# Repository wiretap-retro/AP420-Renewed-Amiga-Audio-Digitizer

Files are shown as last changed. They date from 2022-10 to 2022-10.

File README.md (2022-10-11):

# AP420 Renewed Amiga Audio Digitizer
A remake of the Phoenix Microtechnologies AP420 with mono input and TRS microphone jack.

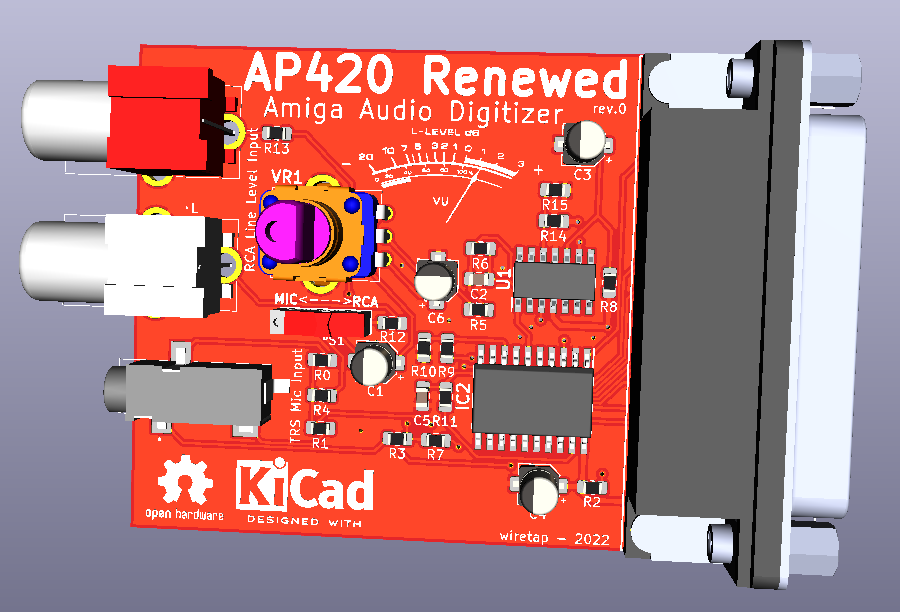
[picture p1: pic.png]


## Information
The schematic is per the PDF manual in the respository from the Phoenix Microtechnologies AP420. I added a second RCA jack so you can hook up stereo sound and it will be combined to a mono input. There's also an updated microphone jack that supports TRS 3.5mm and goes to a mono input. The selector switch on the board allows you to select between the RCA input and the microphone input. VR1 is a gain control knob for adjusting the strength of the audio signal.
\
\
The AP420 manual also goes into some detail in the notes section for performing component changes to allow for different audio sample rates at the expense of audio quality.
\
\
This device hooks up to the parallel port of of an Amiga 500, 600, 1000 (with adapter), 1200, 2000, 3000, and 4000. It does not require any external power.

## Misc
Not built and tested yet. Feel free to evaluate the circuit and provide any feedback.

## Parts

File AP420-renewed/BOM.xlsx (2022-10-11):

Reference | Value | Footprint | Description | Manufacturer_Name | Manufacturer_Part_Number | Mouser Part Number
C1 | 10u | Capacitor_SMD:CP_Elec_4x5.8
C2 | 220p | Capacitor_SMD:C_0805_2012Metric_Pad1.15x1.40mm_HandSolder
C3 | 10u | Capacitor_SMD:CP_Elec_4x5.8
C4 | 10u | Capacitor_SMD:CP_Elec_4x5.8
C5 | 100p | Capacitor_SMD:C_0805_2012Metric_Pad1.15x1.40mm_HandSolder
C6 | 10u | Capacitor_SMD:CP_Elec_4x5.8
IC2 | ADC0804LCWMX_NOPB | SOIC127P1030X265-20N | 8-Bit, 1-Ch P Compatible A/D Converters with 1 LSB INL | Texas Instruments | ADC0804LCWMX/NOPB | 926-ADC0804LCWMXNOPB
J0 | L717SDB25P1ACH4F | L717SDB25P1ACH4F | Dsub, Stamped Signal 3A, Right Angle PCB Through Hole, FP=10.40mm (0.409in), Row Pitch 2.54mm, 25 Pin, Flash Gold, Bright Tin Shell+Grounding Dimples, 4-40 Front Screwlock, Ground Tab with Boardlock | Amphenol | L717SDB25P1ACH4F | 523-L717SDB25P1ACH4F
J1 | SJ-3523-SMT-TR | SJ3523SMTTR | Phone Connectors Audio Jacks | CUI Inc. | SJ-3523-SMT-TR | 490-SJ-3523-SMT-TR
J2 | RCJ-042 | RCJ042 | RCA Phono Connectors RCA Connectors | CUI Inc. | RCJ-042 | 490-RCJ-042
J3 | RCJ-043 | RCJ043 | RCA Phono Connectors RCA Connectors | CUI Inc. | RCJ-042 | 490-RCJ-043
R0 | 10k | Resistor_SMD:R_0805_2012Metric_Pad1.15x1.40mm_HandSolder
R1 | 10k | Resistor_SMD:R_0805_2012Metric_Pad1.15x1.40mm_HandSolder
R10 | 470 | Resistor_SMD:R_0805_2012Metric_Pad1.15x1.40mm_HandSolder
R11 | 1.5k | Resistor_SMD:R_0805_2012Metric_Pad1.15x1.40mm_HandSolder
R12 | 1k | Resistor_SMD:R_0805_2012Metric_Pad1.15x1.40mm_HandSolder
R13 | 1k | Resistor_SMD:R_0805_2012Metric_Pad1.15x1.40mm_HandSolder
R14 | 1M | Resistor_SMD:R_0805_2012Metric_Pad1.15x1.40mm_HandSolder
R15 | 1M | Resistor_SMD:R_0805_2012Metric_Pad1.15x1.40mm_HandSolder
R2 | 2.2k | Resistor_SMD:R_0805_2012Metric_Pad1.15x1.40mm_HandSolder
R3 | 10k | Resistor_SMD:R_0805_2012Metric_Pad1.15x1.40mm_HandSolder
R4 | 1M | Resistor_SMD:R_0805_2012Metric_Pad1.15x1.40mm_HandSolder
R5 | 22k | Resistor_SMD:R_0805_2012Metric_Pad1.15x1.40mm_HandSolder
R6 | 100k | Resistor_SMD:R_0805_2012Metric_Pad1.15x1.40mm_HandSolder
R7 | 22k | Resistor_SMD:R_0805_2012Metric_Pad1.15x1.40mm_HandSolder
R8 | 3.3k | Resistor_SMD:R_0805_2012Metric_Pad1.15x1.40mm_HandSolder
R9 | 1.5k | Resistor_SMD:R_0805_2012Metric_Pad1.15x1.40mm_HandSolder
S1 | 450301014042 | 450301014042 | Mini Slide Switch 10x2.5mm SPDT on / on Through Hole Slide Switch SPDT On-On 100 mA@ 42 V dc Slide | Wurth Elektronik | 450301014042 | 710-450301014042
U1 | LM324DR | SamacSys_Parts:SOIC127P600X175-14N | Operational Amplifiers - Op Amps Quad GP Op Amp | Texas Instruments | LM324DR | 595-LM324DR
VR1 | RK09D1130C1B | RK09D1130C1B | Audio single pot. 10K Vertical 20mm,1B Alps Potentiometer RK09D Series with a 6 mm Dia. Shaft 10k +/-20% 0.05W, Linear, Through Hole | ALPS Electric | RK09D1130C1B | 688-RK09D1130C1B

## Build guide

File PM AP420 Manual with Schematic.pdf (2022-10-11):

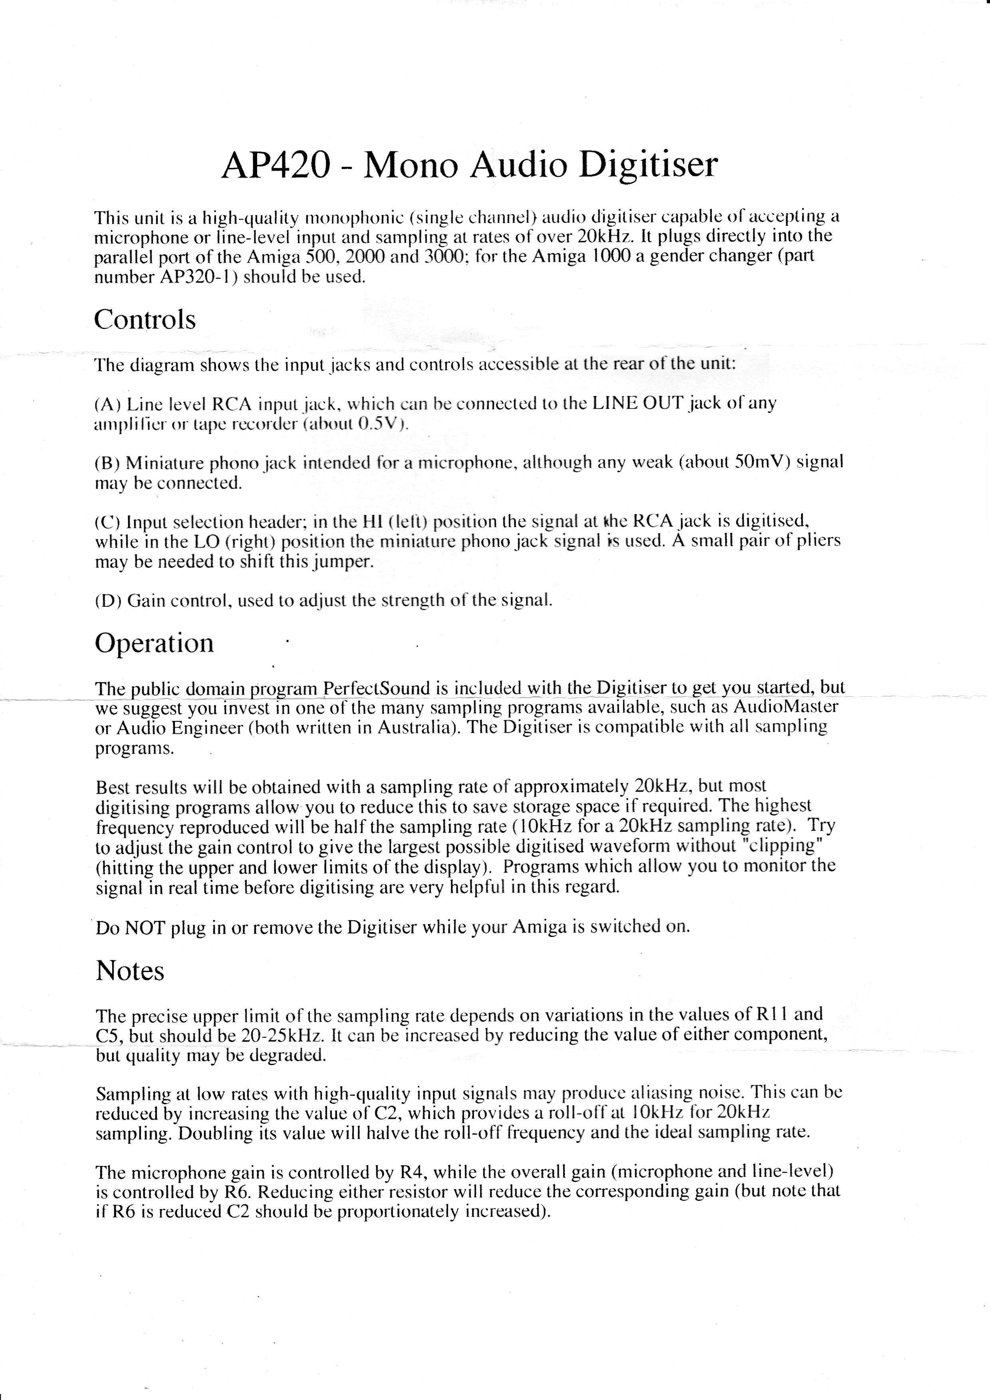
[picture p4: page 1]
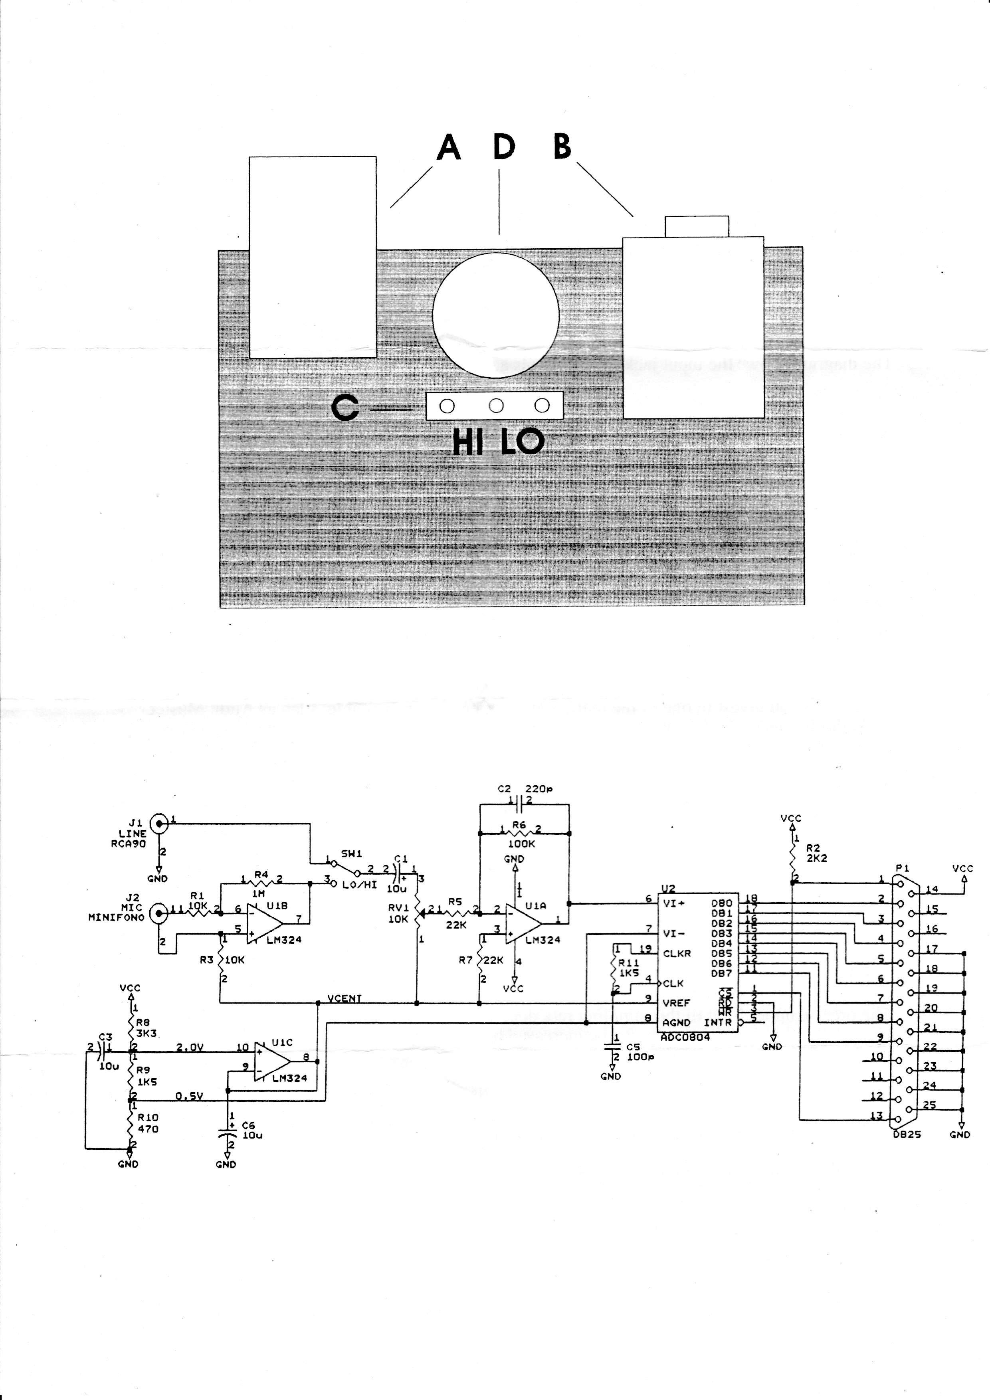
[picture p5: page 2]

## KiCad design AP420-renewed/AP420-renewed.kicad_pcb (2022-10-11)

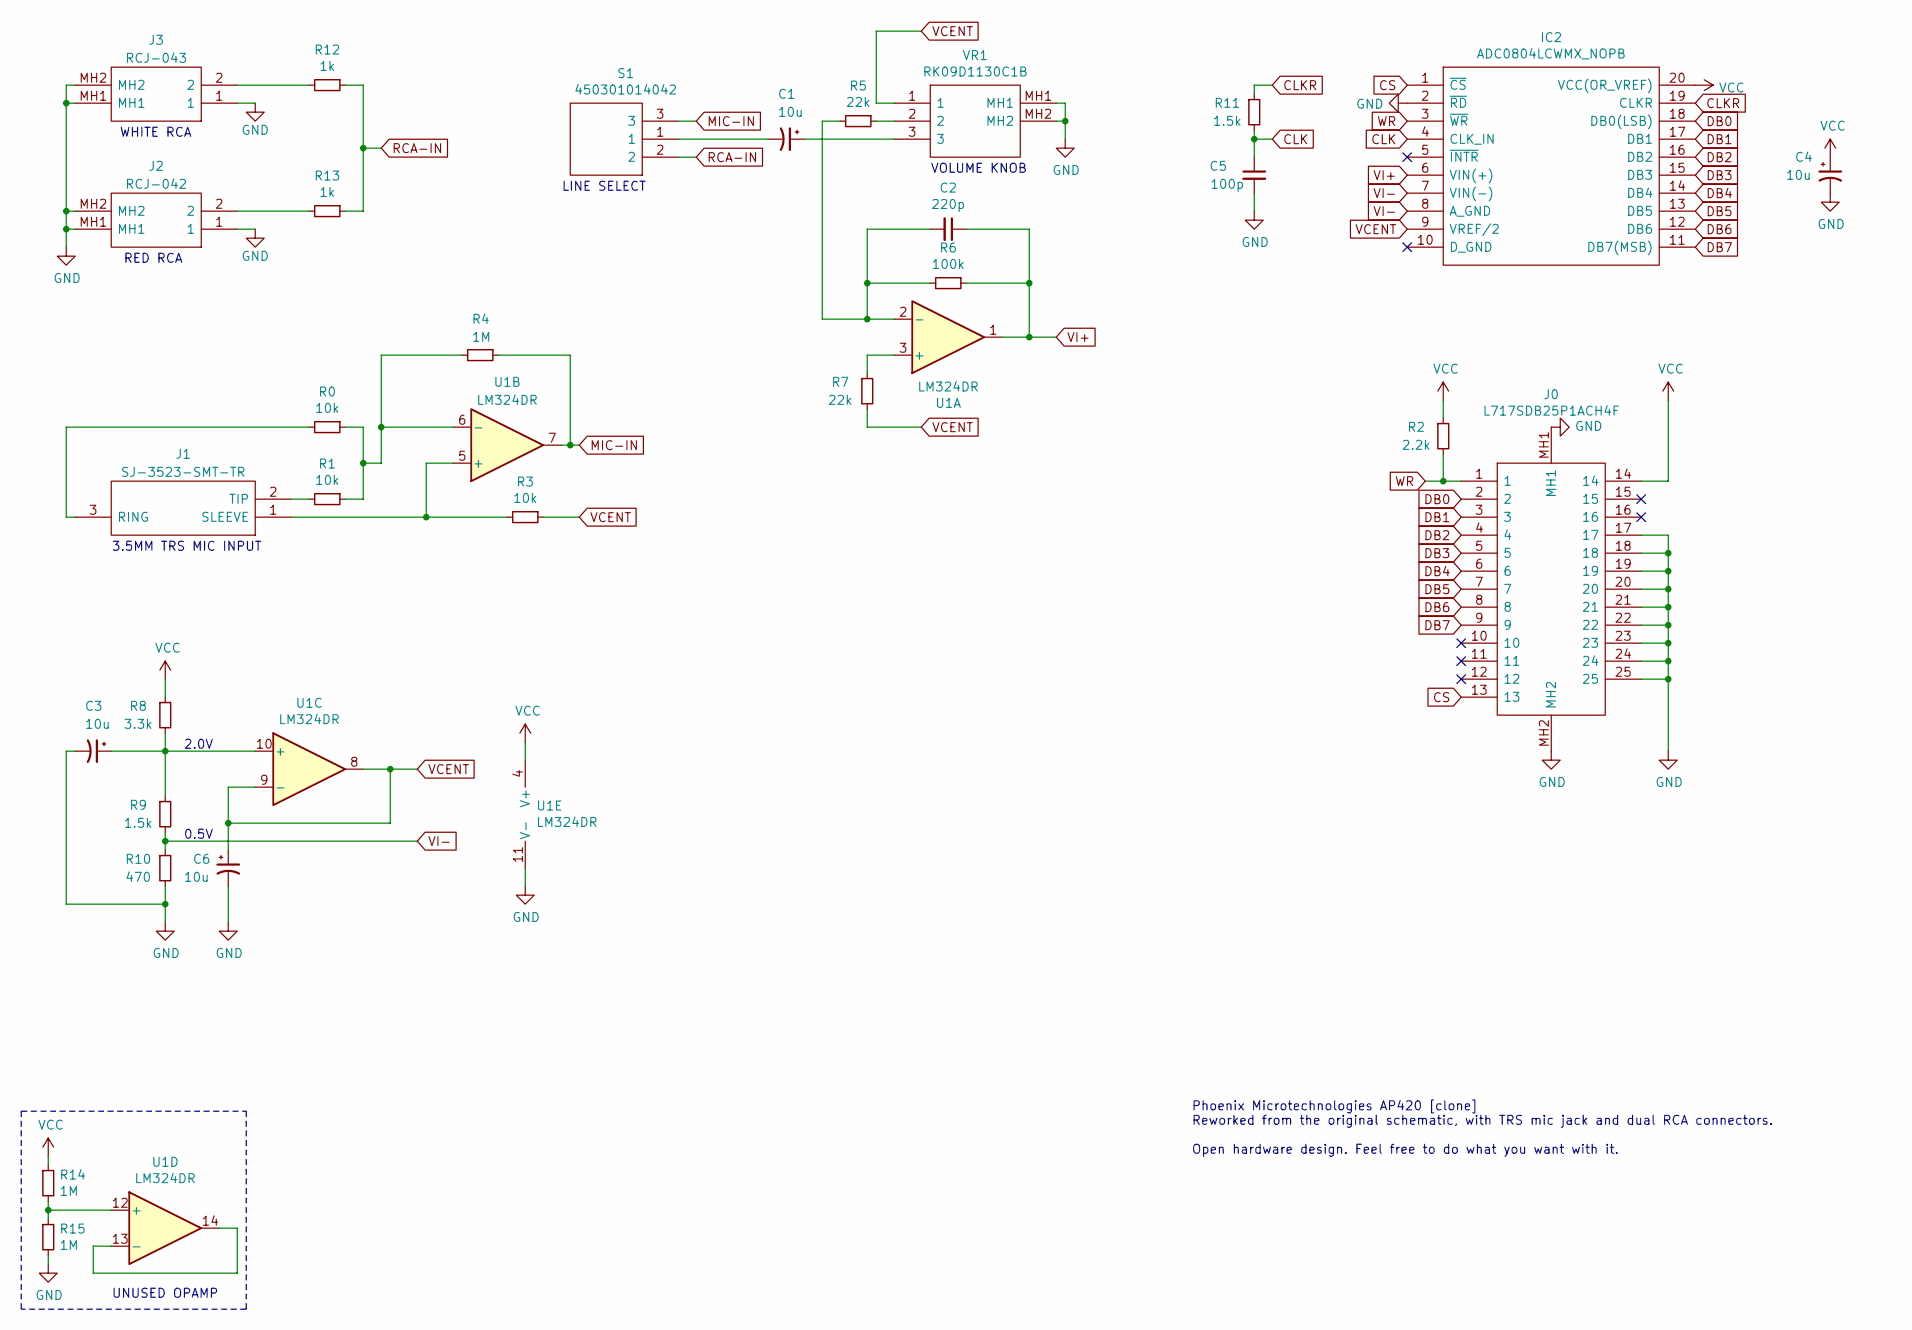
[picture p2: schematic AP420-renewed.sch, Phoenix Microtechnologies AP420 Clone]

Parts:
C1, C3, C4, C6: 10u; CP_Elec_4x5.8
C2: 220p; C_0805_2012Metric_Pad1.15x1.40mm_HandSolder
C5: 100p; C_0805_2012Metric_Pad1.15x1.40mm_HandSolder
IC2: ADC0804LCWMX_NOPB; SOIC127P1030X265-20N; Mouser Part Number 926-ADC0804LCWMXNOPB
J0: L717SDB25P1ACH4F; Mouser Part Number 523-L717SDB25P1ACH4F
J1: SJ-3523-SMT-TR; SJ3523SMTTR; Mouser Part Number 490-SJ-3523-SMT-TR
J2: RCJ-042; RCJ042; Mouser Part Number 490-RCJ-042
J3: RCJ-043; RCJ043; Mouser Part Number 490-RCJ-043
R0, R1, R3: 10k; R_0805_2012Metric_Pad1.15x1.40mm_HandSolder
R2: 2.2k; R_0805_2012Metric_Pad1.15x1.40mm_HandSolder
R4, R14, R15: 1M; R_0805_2012Metric_Pad1.15x1.40mm_HandSolder
R5, R7: 22k; R_0805_2012Metric_Pad1.15x1.40mm_HandSolder
R6: 100k; R_0805_2012Metric_Pad1.15x1.40mm_HandSolder
R8: 3.3k; R_0805_2012Metric_Pad1.15x1.40mm_HandSolder
R9, R11: 1.5k; R_0805_2012Metric_Pad1.15x1.40mm_HandSolder
R10: 470; R_0805_2012Metric_Pad1.15x1.40mm_HandSolder
R12, R13: 1k; R_0805_2012Metric_Pad1.15x1.40mm_HandSolder
S1: 450301014042; Mouser Part Number 710-450301014042
U1: LM324DR; SOIC127P600X175-14N
VR1: RK09D1130C1B; Mouser Part Number 688-RK09D1130C1B

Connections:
CLK: C5.1, IC2.4 (CLK_IN), R11.2
CLKR: IC2.19 (CLKR), R11.1
CS: IC2.1 (~CS), J0.13
DB0: IC2.18 (DB0(LSB)), J0.2
DB1: IC2.17 (DB1), J0.3
DB2: IC2.16 (DB2), J0.4
DB3: IC2.15 (DB3), J0.5
DB4: IC2.14 (DB4), J0.6
DB5: IC2.13 (DB5), J0.7
DB6: IC2.12 (DB6), J0.8
DB7: IC2.11 (DB7(MSB)), J0.9
GND: C3.2, C4.2, C5.2, C6.2, IC2.2 (~RD), J0.17, J0.18, J0.19, J0.20, J0.21, J0.22, J0.23, J0.24, J0.25, J0.MH1, J0.MH2, J2.1, J2.MH1, J2.MH2, J3.1, J3.MH1, J3.MH2, R10.2, R15.2, U1.11 (V-), VR1.MH1, VR1.MH2
MIC-IN: R4.1, S1.3, U1.7
unnamed: C1.1, VR1.3
unnamed: C1.2, S1.1
unnamed: C2.2, R5.2, R6.2, U1.2 (-)
unnamed: C3.1, R8.2, R9.1, U1.10 (+)
unnamed: J1.1 (SLEEVE), R3.2, U1.5 (+)
unnamed: J1.2 (TIP), R1.2
unnamed: J1.3 (RING), R0.2
unnamed: J2.2, R13.2
unnamed: J3.2, R12.2
unnamed: R0.1, R1.1, R4.2, U1.6 (-)
unnamed: R5.1, VR1.2
unnamed: R7.1, U1.3 (+)
unnamed: R14.2, R15.1, U1.12 (+)
unnamed: U1.13 (-), U1.14
RCA-IN: R12.1, R13.1, S1.2
VCC: C4.1, IC2.20 (VCC(OR_VREF)), J0.14, R2.1, R8.1, R14.1, U1.4 (V+)
VCENT: C6.1, IC2.9 (VREF/2), R3.1, R7.2, U1.8, U1.9 (-), VR1.1
VI+: C2.1, IC2.6 (VIN(+)), R6.1, U1.1
VI-: IC2.7 (VIN(-)), IC2.8 (A_GND), R9.2, R10.1
WR: IC2.3 (~WR), J0.1, R2.2

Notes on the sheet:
UNUSED OPAMP
3.5MM TRS MIC INPUT
WHITE RCA
RED RCA
LINE SELECT
VOLUME KNOB
0.5V
2.0V
Phoenix Microtechnologies AP420 [clone] Reworked from the original schematic, with TRS mic jack and dual RCA connectors. Open hardware design. Feel free to do what you want with it.

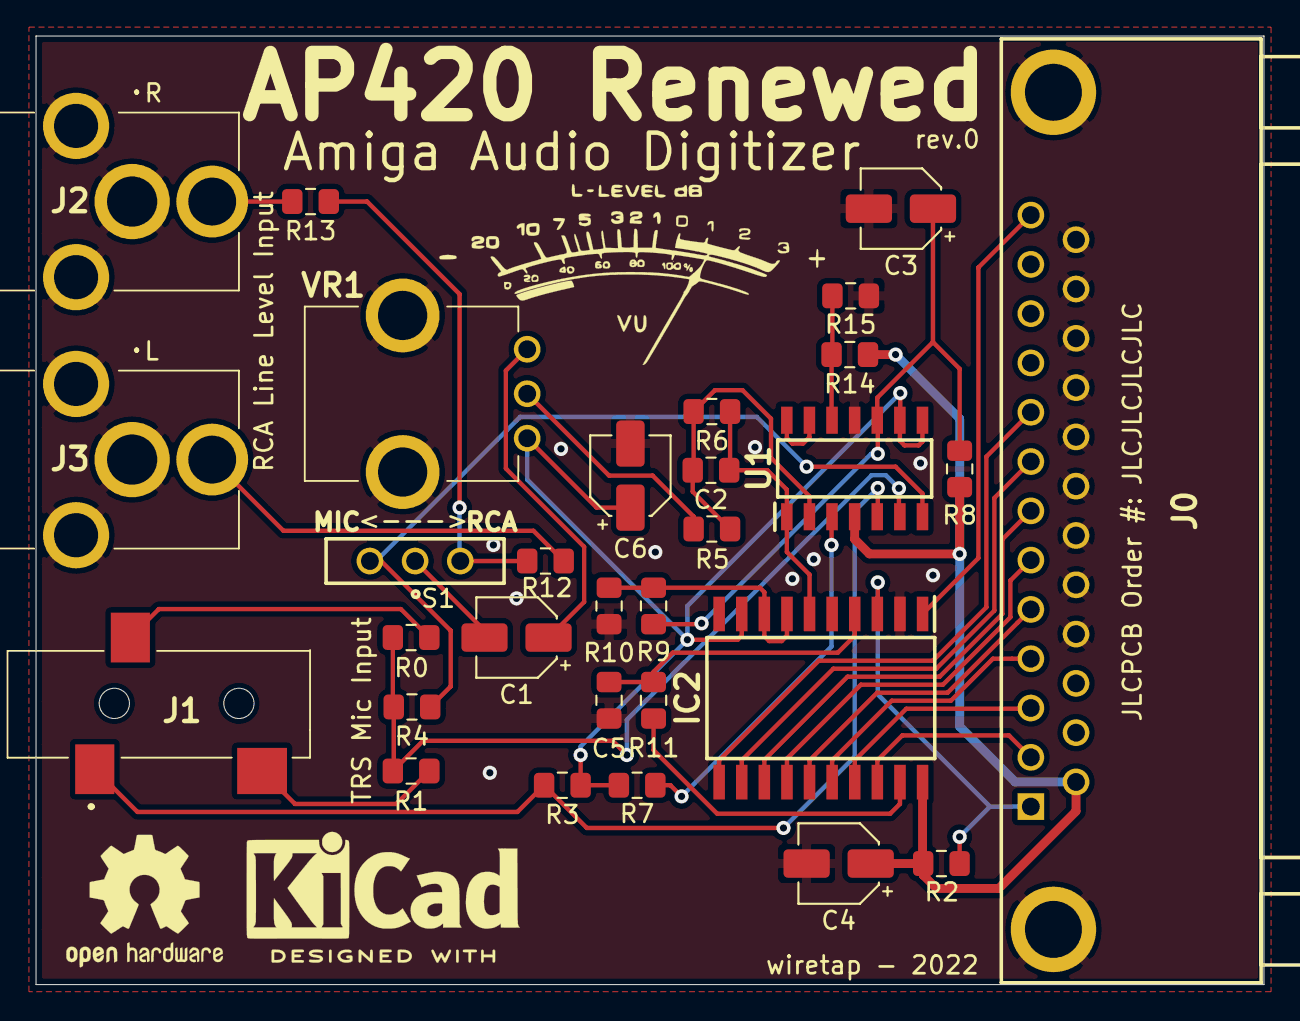
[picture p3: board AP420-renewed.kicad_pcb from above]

Board: 2 copper layers, 69.0 x 53.3 mm, 30 parts (0 on the bottom side), 33 nets.
